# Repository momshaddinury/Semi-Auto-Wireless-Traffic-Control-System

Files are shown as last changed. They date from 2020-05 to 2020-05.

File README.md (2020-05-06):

# Project Name - Lora based Taffic Control System

## Project Members:
* Momshad Dinury
* Abdullah Zowad Khan
* Towqir Ahmed Shaem

## Project Description:
The system is built using devices of two types: node and controller; one controller per system and a maximum of four nodes connected to it. The controller device uses an esp32, a dual-core SoC, with wifi and bluetooth functionalities. The system uses a NEXTION display for the status of the nodes associated with it. For the communication side, LoRa (Long Range) radio module is used. LoRa is widely known for its efficiency in sending short messages quickly and reliably. LoRa uses a transmission method called Chirp Spread Spectrum (CSS) which is used mostly in military and space communications for low power solutions. And lastly, in the nodes, ESP8266 and LoRa are used.

The process begins with the controller rebooting and syncing the nodes. The reboot and sync is done to ensure there is no data loss in regular operations. Each node upon reboot sends a successful boot message, which is used to show the status of the mentioned node.

The signaling is done by pressing specific buttons on the controller. Upon pressing, the controller sends the appropriate signal to the node through LoRa. The system has a timeout of ~15 seconds on communication, after that the attempt is marked as failed. After the node receives the signal, it switches the LEDs on the node then transmits appropriate acknowledgment packets. The display on the controller has a timer so the operator can easily decide whether enough time has passed for a given state at a given lane. The signals sent to each node are independent of the others, which allows the operator to shut down all lanes in case of an emergency.

## Shortcuts
* [**Controller Algorithm Overview**](#controller-algorithm-overview)
* [**Node Algorithm Overview**](#node-algorithm-overview)

## Controller Details

[**Controller.ino**](https://gitlab.com/Momshad/Lora-Traffic-Control-System/blob/Controller-Adjustments-Timers-Displays/Controller/Controller.ino)

### Interrupt Handlers

```cpp
void ISR_DB_1();
void ISR_DB_2();
void ISR_DB_3();
```

Display timers attached to:
```cpp
void Setting_Block_State_Color();
void showTime();
```

## Version 1 Configuration

* Display - TFT
* MCU - esp8266
* Communication - RF (LoRa Module)

## Version 2 Configuration

* Display - 4 Nokia 5110 Transflective Display
* MCU - ESP32
* Communication - Unchanged

### Controller Algorithm Overview
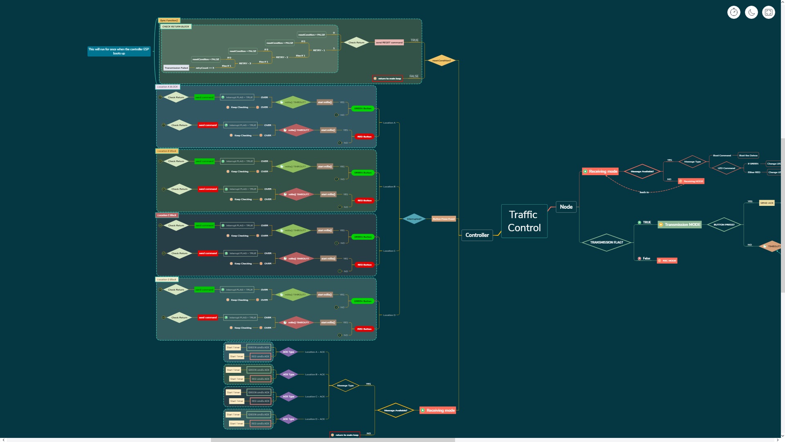
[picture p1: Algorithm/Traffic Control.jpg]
Controller Algorithm


### Node Algorithm Overview
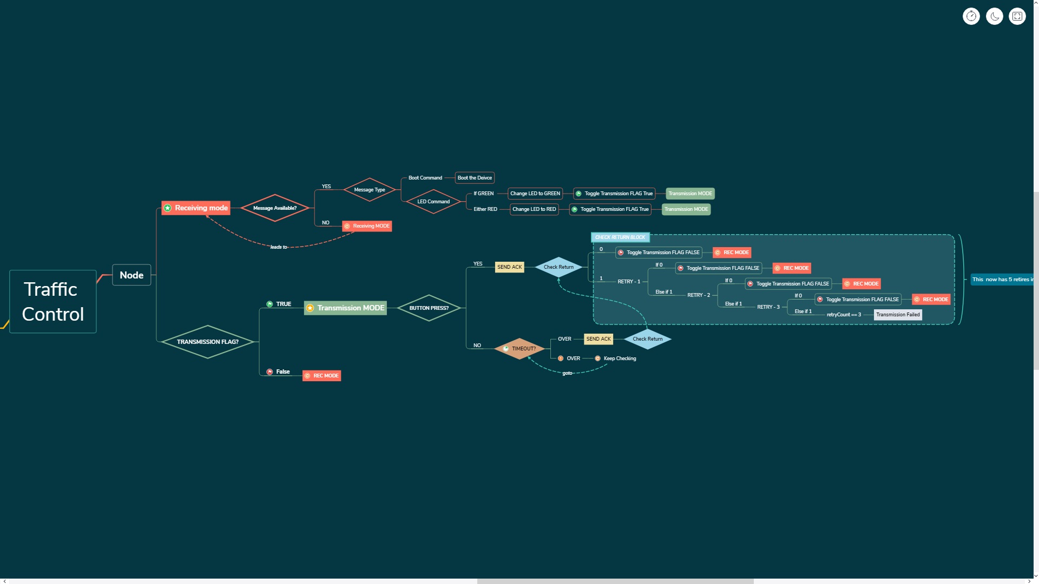
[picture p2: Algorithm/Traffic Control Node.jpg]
Node Algorithm


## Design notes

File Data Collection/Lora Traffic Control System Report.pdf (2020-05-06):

## LoRa Traffic Control System - Project Report

## Current Consumption:

Device | Components | Current Consumption
Controller | Lora | Idle: 14mA

Active: 14mA

NextIon Display | Idle: 107- 110mA
| During changes: 107-112mA
Total Current Consumption | 130mA
Wand | Active State | 160-180mA
| Idle State | 82mA

## Live Test Report:

We tested our device for half an hour in 2 No Gate Circle. It was successful but police recommended few features.

Features Needed:
1. Their baton has the following features:
a. Button pressed, One time - Baton lights up. (Max brightness)
b. Pressed again - Baton light dims slightly.
c. Pressed again - Baton blinks rapidly. (Means emergency)
d. Pressed again - Baton light goes to normal mode and turns on the torch
e. Pressed again - Turns off everything
f. They have another separate button that works as a whistle. In total two buttons
g. Two Day Battery backup.
2. Traffic Control Algorithm: Our algorithm controls each lane individually. But in reality, sergeant controls traffic using a two-stage method. Look at the picture. Sergeant closes TL3 and TL4 opens TL2 and
TL1. When TL3 and TL4
opens they close TL1 and
TL2. So basically it’s simple two-stage control method.
Whereas our controller
controls each lane
individually.

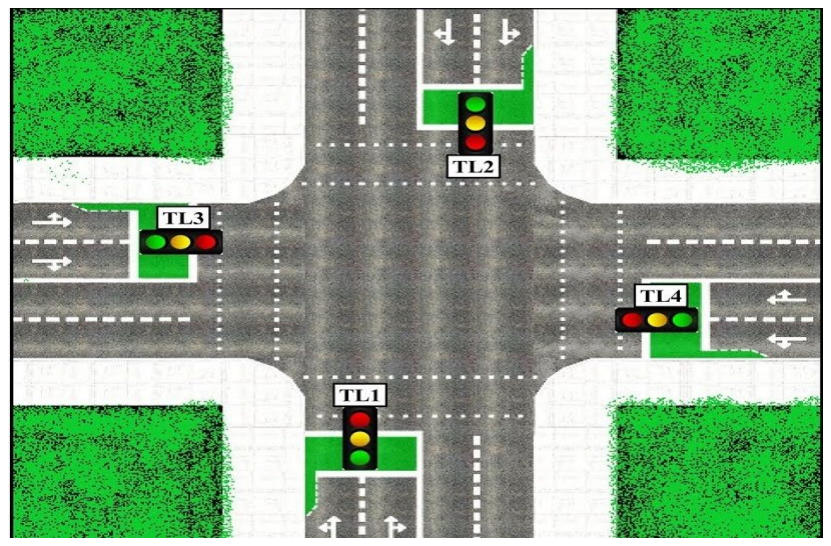
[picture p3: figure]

3. The controller controls baton state as of now, but we need to control Traffic Lights simultaneously with the baton. Basically, one command will change the state of Baton and Traffic Light simultaneously.
4. Automation system. We need to give Sergeant an option that will allow him to automate traffic control. This will be helpful if they are short in the manpower department or if they want to take a break. They can initiate automation mode.
5. The controller needs to be small, easy to carry and lightweight.
6. We need to increase the sunlight visibility of the NextIon Display. ( Using brighter indicator color)

Data: (Link: Data Sheet) (https://docs.google.com/spreadsheets/d/1eQOcHfU4sZK29l6jYq9fvzXtCkEq3vm5WKsJ4Qx3BQA/edit?usp=sharing)

For FSK mode:

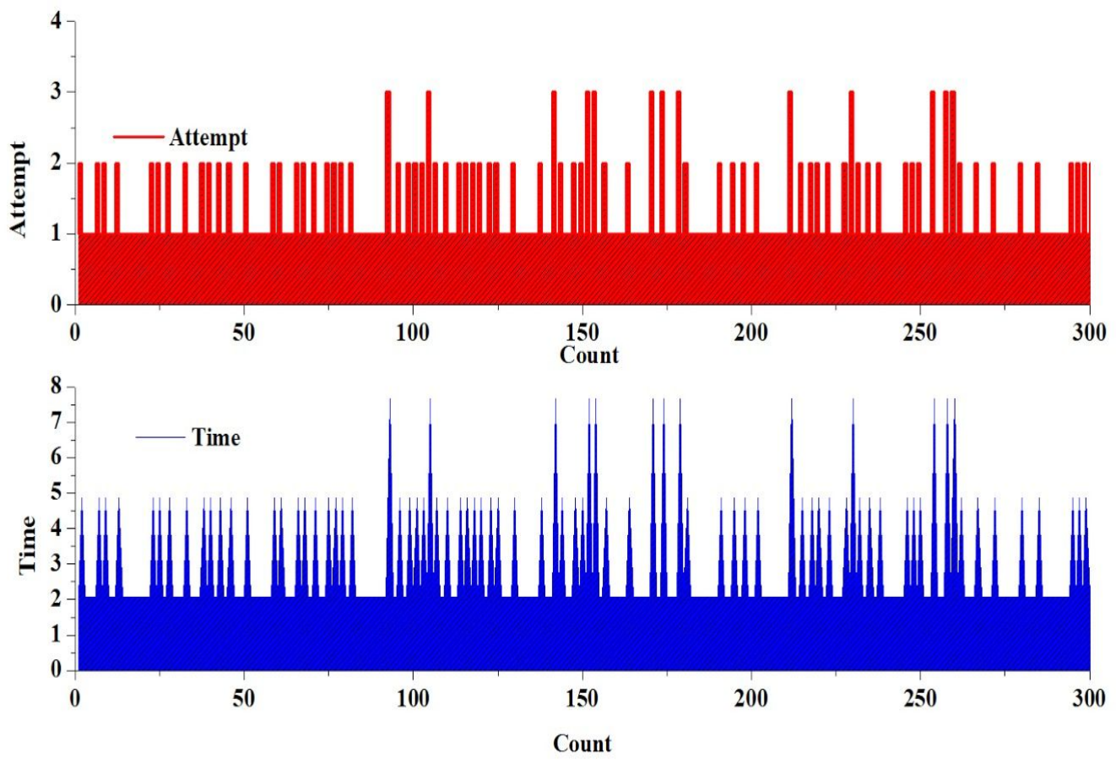
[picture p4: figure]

Time Comparison in OOK mode:

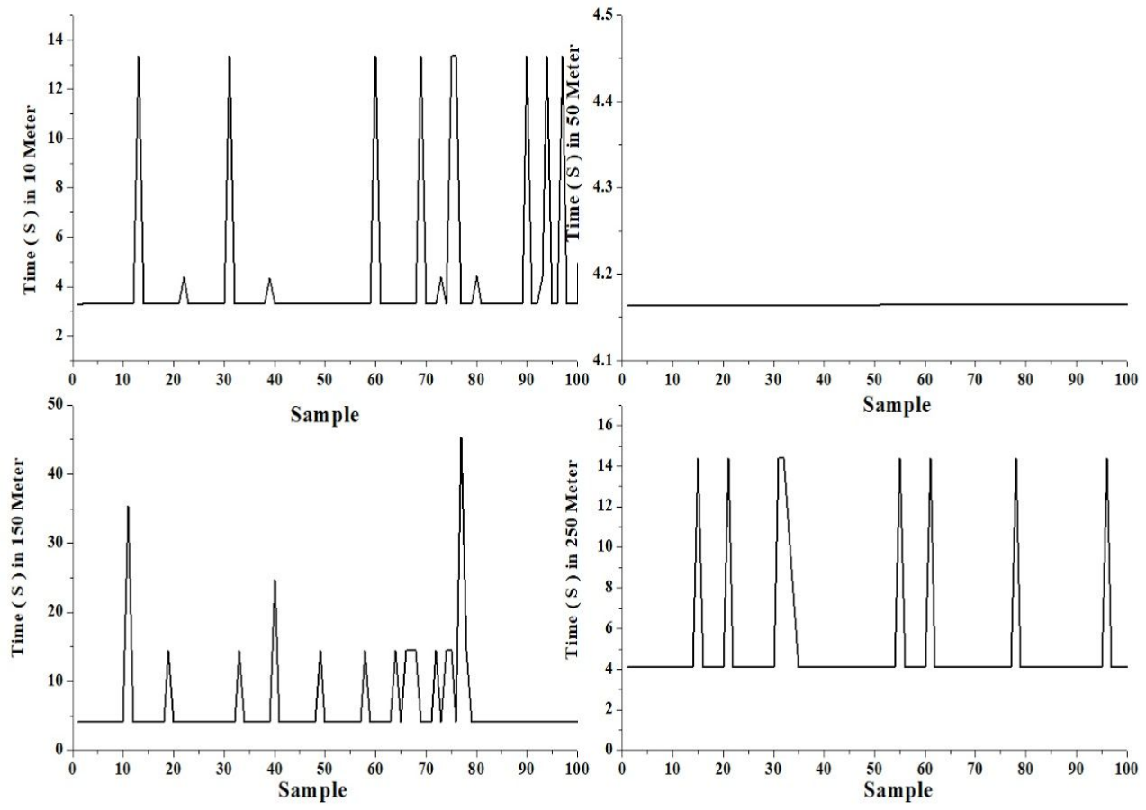
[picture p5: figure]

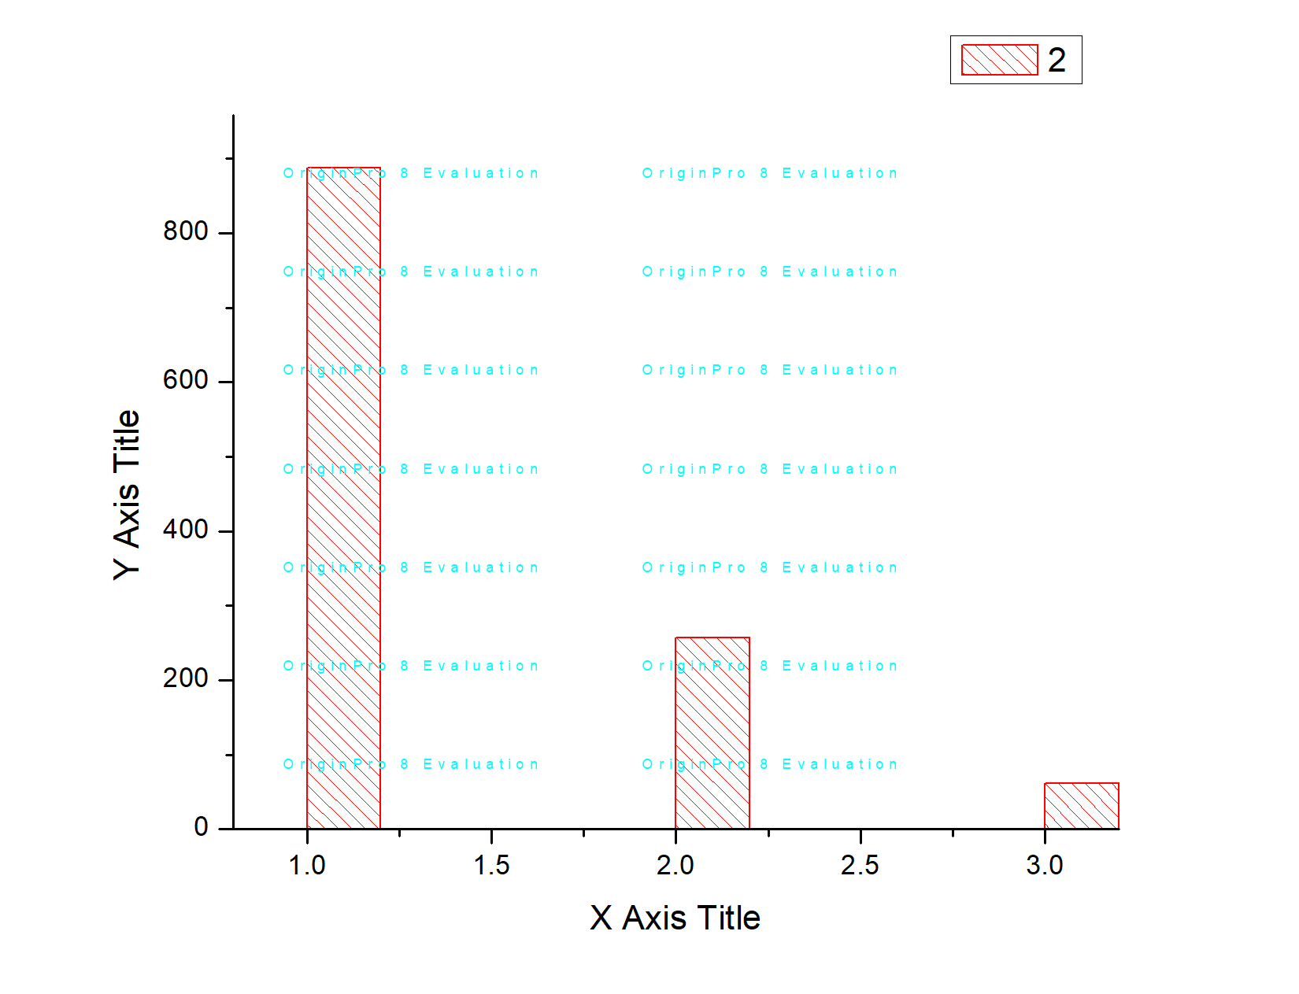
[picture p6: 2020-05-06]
Data Collection/Graph and Corelations/Attempts.jpg

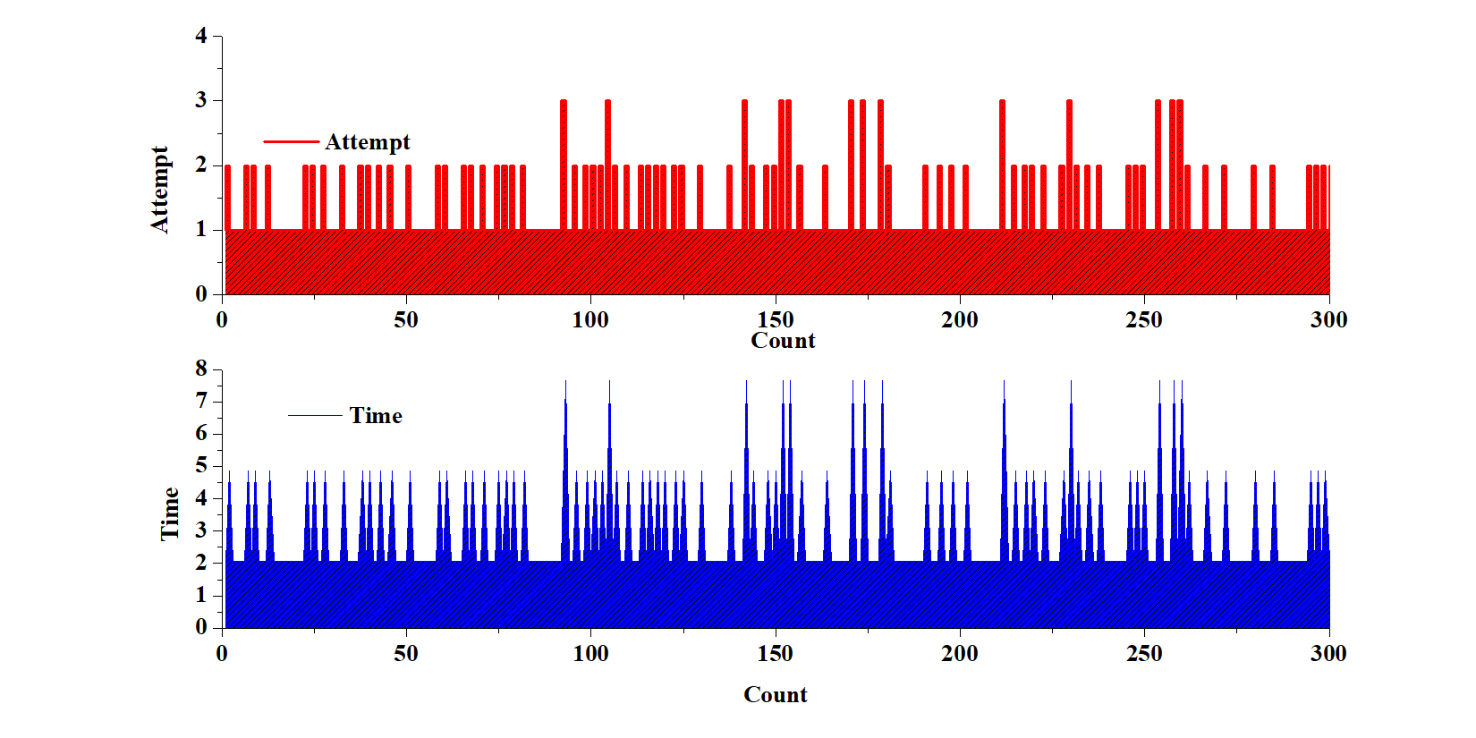
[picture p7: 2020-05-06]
Data Collection/Graph and Corelations/Attemt and Time Vs Counting In FSK.jpg

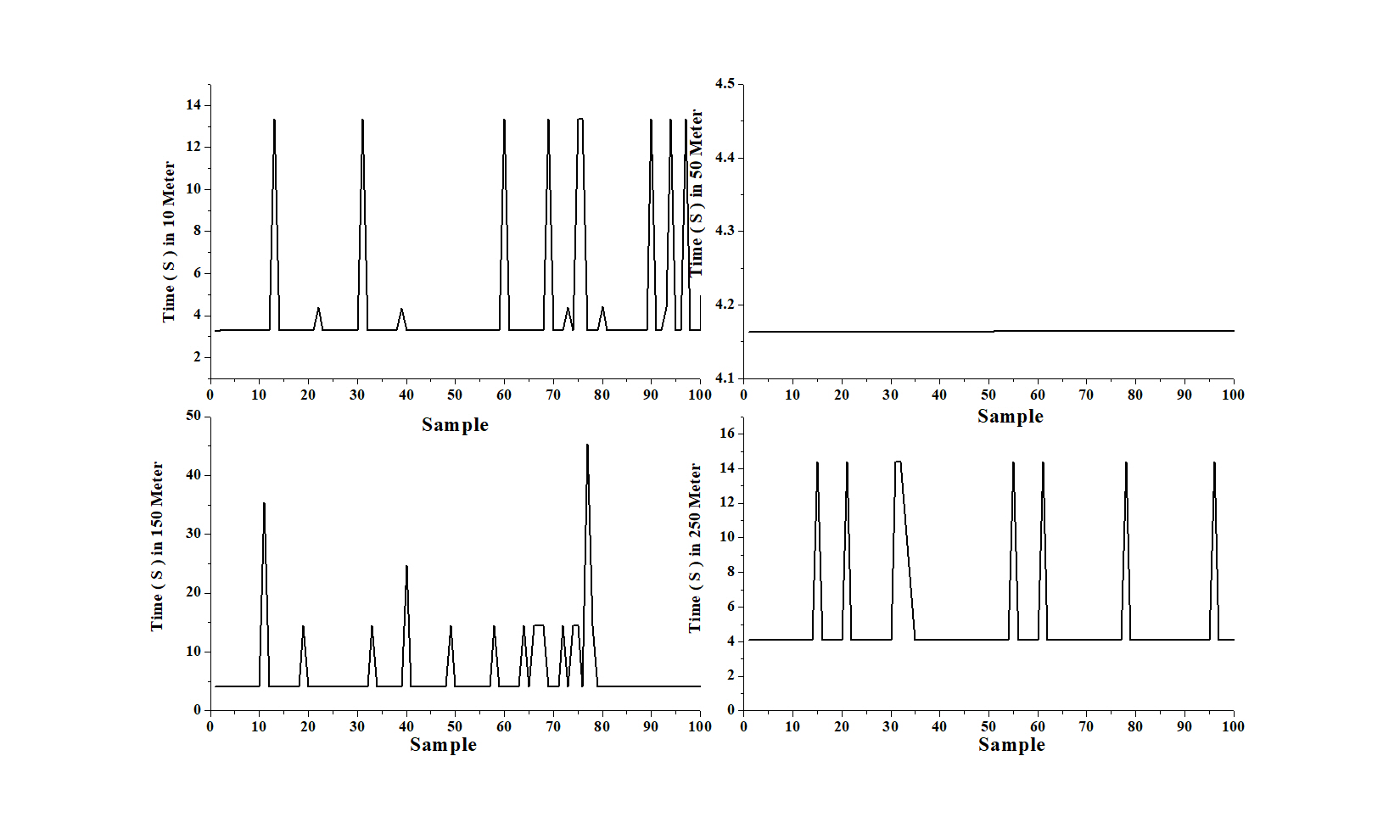
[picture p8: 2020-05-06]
Data Collection/Graph and Corelations/Time Comparision in Distance.jpg

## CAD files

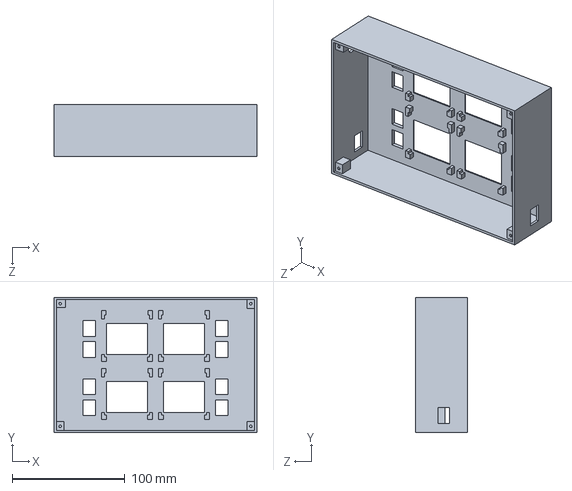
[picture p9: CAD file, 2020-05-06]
3D Design/Controller Box/Box.SLDPRT
180.0 x 120.0 x 46.0 mm

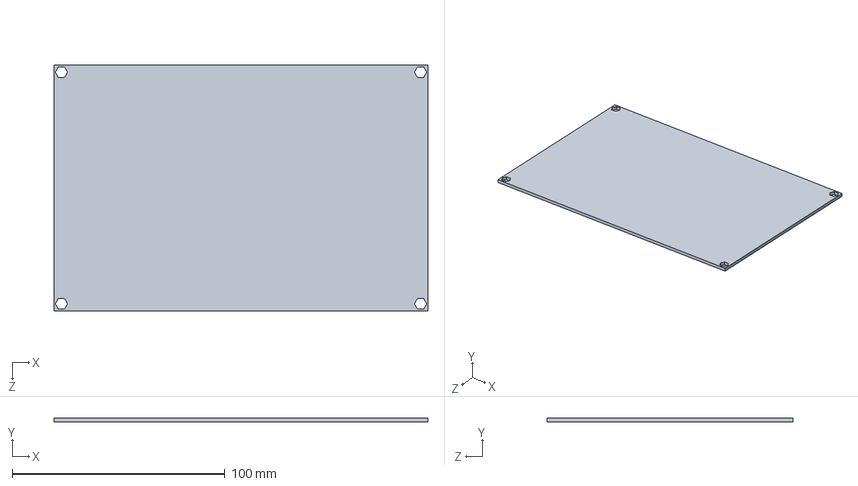
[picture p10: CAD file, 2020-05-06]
3D Design/Controller Box/Bottom Plate.SLDPRT
176.0 x 2.00 x 116.0 mm

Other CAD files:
3D Design/Controller Box/Bottom Plate.STL
3D Design/Controller Box/Box.STL

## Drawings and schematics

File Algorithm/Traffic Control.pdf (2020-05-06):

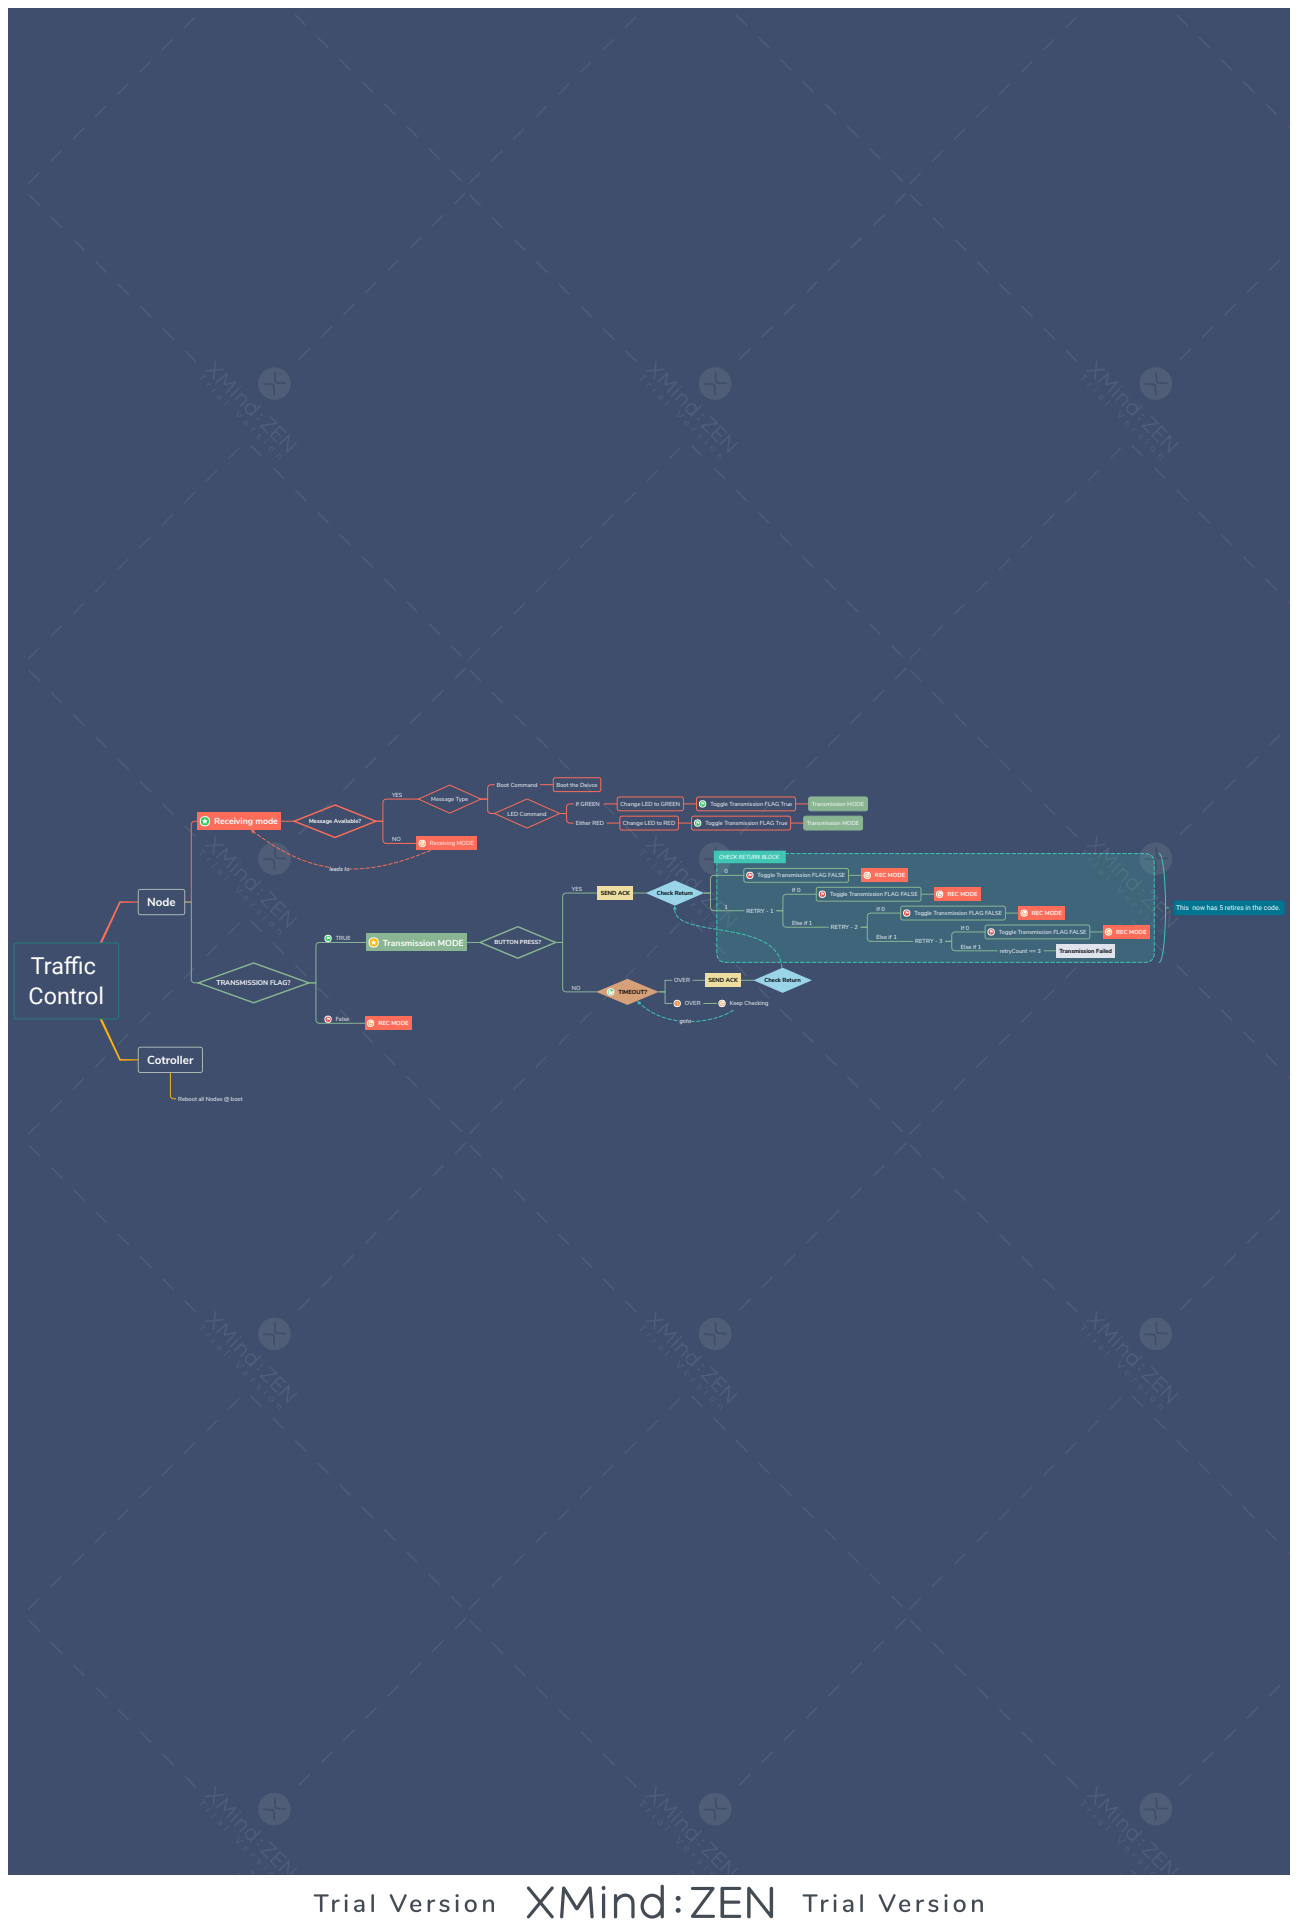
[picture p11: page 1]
Traffic Control; Node; Receiving mode; Message Available?; YES; Message Type; Boot Command; Boot the Deivce; LED Command; If GREEN; Change LED to GREEN; Toggle Transmission FLAG True; Transmission MODE; Either RED; Change LED to RED; Receiving MODE; TRANSMISSION FLAG?; TRUE; BUTTON PRESS?; SEND ACK; Check Return; RETRY - 1; Else if 1; RETRY - 2; RETRY - 3; retryCount == 3; Transmission Failed; TIMEOUT?; OVER; Keep Checking; False; REC MODE; Cotroller; leads to; goto

CHECK RETURN BLOCK

Toggle Transmission FLAG FALSE

This now has 5 retires in the code.

Reboot all Nodes @ boot

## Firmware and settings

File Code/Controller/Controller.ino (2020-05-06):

// ---------------------------------------------------------------------
/*
  Project Name - Semi Automatic Traffic Control System using Lora SX1278
  Components used:
           MCU - ESP32
           Communication module - Lora SX1278 ( FDK Mode )
           Indicator - LED Custom Made Strip
           Power Source - LC 18650
  Author - Momshad Dinury
  Contributor:
           Towqir Ahmed Shaem
           Abdullah Zawad Khan
*/
// ---------------------------------------------------------------------

/******************************************************************************
   Includes
 ******************************************************************************/
#include <Arduino.h>
//Lora SX1278:
#include <SX1278.h>
//Library for Ticker
#include <Ticker.h>
//Library for Display
#include <U8g2lib.h>
#include <WiFi.h>

/*****************************************************************************
   Definitions & Declarations
 *****************************************************************************/

U8G2_PCD8544_84X48_F_4W_HW_SPI u8g1(U8G2_R0, /* cs=*/2, /* dc=*/23, /* reset=*/100);  // Nokia 5110 Display
U8G2_PCD8544_84X48_F_4W_HW_SPI u8g2(U8G2_R0, /* cs=*/4, /* dc=*/23, /* reset=*/100);  // Nokia 5110 Display
U8G2_PCD8544_84X48_F_4W_HW_SPI u8g3(U8G2_R0, /* cs=*/15, /* dc=*/23, /* reset=*/100); // Nokia 5110 Display
U8G2_PCD8544_84X48_F_4W_HW_SPI u8g4(U8G2_R0, /* cs=*/17, /* dc=*/23, /* reset=*/100); // Nokia 5110 Display

//Lora SX1278:
#define LORA_MODE 4
#define LORA_CHANNEL CH_6_BW_125
#define LORA_ADDRESS 5
uint8_t NodeAddress; //Child Address
int address;

#define ADDR_1_INT 3
#define ADDR_1_STR "  GEC CIRCLE"

#define ADDR_2_INT 4
#define ADDR_2_STR "      BAYEZID"

#define ADDR_3_INT 6
#define ADDR_3_STR "      OXYGEN"

#define ADDR_4_INT 7
#define ADDR_4_STR "  MURADPUR"

//Packets var:
char my_packet[50];
char testData[50];
String receivedMsg;
int T_packet_state;
int R_packet_state;

//Pin def of Switch:

#define digitalButton_1 25
#define digitalButton_2 26
#define digitalButton_3 32
#define digitalButton_4 33
#define digitalButton_5 18
#define digitalButton_6 19
#define digitalButton_7 21
#define digitalButton_8 22

// #define digitalButton_3 5
//Experimental

//Signal Time Var:
unsigned long DB_1_Signal_Runtime, DB_2_Signal_Runtime, DB_3_Signal_Runtime, DB_4_Signal_Runtime;
unsigned long currentMil;

//Experimental variables, Color Flags
int colorRG1 = 1, colorRG2 = 1, colorRG3 = 1, colorRG4 = 1;
const int R = 1;
const int G = 2;
const int X = 0;

int attemptDebug = 0;

Ticker location1Sec;

//Sync:
boolean resetCondition = true;

//Timer used to stop debounce @Interrupt Button Press:
long interval = 3000;
volatile unsigned long DB_priv_time_1;
volatile unsigned long DB_priv_time_2;
volatile unsigned long DB_priv_time_3;
volatile unsigned long DB_priv_time_4;
//Interrupt Flag @ISRs Function:
volatile boolean DB_ISR_F_1 = false;
volatile boolean DB_ISR_F_2 = false;
volatile boolean DB_ISR_F_3 = false;
volatile boolean DB_ISR_F_4 = false;

// Button State var @ISRs function:
boolean button1State = true;
boolean button2State = true;
boolean button3State = true;
boolean button4State = true;

boolean is1First = true;
boolean is2First = true;
boolean is3First = true;
boolean is4First = true;

boolean isSyncDone = false;
boolean is1Active = false;
boolean is2Active = false;
boolean is3Active = false;
boolean is4Active = false;

//Transmission Time Calculation Var @InterruptAction():
unsigned long DB_1_Process_Start_Time;
unsigned long DB_1_Process_End_Time;
unsigned long DB_2_Process_Start_Time;
unsigned long DB_2_Process_End_Time;
unsigned long DB_3_Process_Start_Time;
unsigned long DB_3_Process_End_Time;
unsigned long DB_4_Process_Start_Time;
unsigned long DB_4_Process_End_Time;

//Automatic Transmission Flags and Var:
// #define automation
long int autoTime1 = 0;
long int autoTime2 = 0;

//*****
int signalTimeCount = 0;

//Serial Print and Debug:
#define DEBUG
//TESTCASE:
//#define TEST
//#define TESTDEBUG

float t_time;
//Block State Color:
boolean blockStateColor;
int count = 0;

boolean isTransmissionInProgress = false;
boolean isTransmissionInProgress_1 = false;
boolean isTransmissionInProgress_2 = false;
boolean isTransmissionInProgress_3 = false;
boolean isTransmissionInProgress_4 = false;
int countDebug = 1;

//MAIN SETUP FUNCTION
void setup()
{
  // #ifdef DEBUG
  Serial.begin(9600);
  // #endif
  WiFi.mode(WIFI_OFF);
  btStop();
  delay(2000);

  //Display Setup:
  displaySetup();

  // Lora Initialization
  loraSetup();

  //PinMode:
  // 1 Button:
  pinMode(digitalButton_1, INPUT_PULLUP);
  pinMode(digitalButton_2, INPUT_PULLUP);
  // 2 Button:
  pinMode(digitalButton_3, INPUT_PULLUP);
  pinMode(digitalButton_4, INPUT_PULLUP);
  // 3 Button:
  pinMode(digitalButton_5, INPUT_PULLUP);
  pinMode(digitalButton_6, INPUT_PULLUP);
  // 4 Button:
  pinMode(digitalButton_7, INPUT_PULLUP);
  pinMode(digitalButton_8, INPUT_PULLUP);

  pinMode(27, OUTPUT);
  digitalWrite(27, LOW); // To Light Up The Display.

  //Initialization of timers
  DB_1_Signal_Runtime = millis(); //L 1
  DB_2_Signal_Runtime = millis(); //L 2
  DB_3_Signal_Runtime = millis();
  DB_4_Signal_Runtime = millis();

  colorRG1 = X; //L 1
  colorRG2 = X; //L 2
  colorRG3 = X;
  colorRG4 = X;

  //Interrupt Experimental
  attachInterrupt(digitalPinToInterrupt(digitalButton_1), ISR_DB_1_G_32, FALLING);
  attachInterrupt(digitalPinToInterrupt(digitalButton_2), ISR_DB_1_R_32, FALLING);
  attachInterrupt(digitalPinToInterrupt(digitalButton_3), ISR_DB_2_G_32, FALLING);
  attachInterrupt(digitalPinToInterrupt(digitalButton_4), ISR_DB_2_R_32, FALLING);
  attachInterrupt(digitalPinToInterrupt(digitalButton_5), ISR_DB_3_G_32, FALLING);
  attachInterrupt(digitalPinToInterrupt(digitalButton_6), ISR_DB_3_R_32, FALLING);
  attachInterrupt(digitalPinToInterrupt(digitalButton_7), ISR_DB_4_G_32, FALLING);
  attachInterrupt(digitalPinToInterrupt(digitalButton_8), ISR_DB_4_R_32, FALLING);
}

//MAIN LOOP
void loop()
{
  //After the device is booted it automatically re-boots other device:
  sync();

  //  if (countDebug % 2 == 0) ISR_DB_3_G_32();
  //  else ISR_DB_3_R_32();
  //autoTransmission();
  InterruptAction();

  //This function checks for data to receive
  //  if (!isSyncDone)
  //  {
  receiveSync();
  //  }
  //  else recieveData();

  //Show time on display:
  showTime();
  //  delay(500);
}

//RESETs connected Nodes
void sync()
{
  if (resetCondition == true)
  {

    String("S").toCharArray(testData, 50);
    address = ADDR_1_INT;
    sendData2(ADDR_1_INT, testData);
    delay(500);

    receiveSync();

    address = ADDR_2_INT;
    sendData2(ADDR_2_INT, testData);
    delay(500);

    receiveSync();

    address = ADDR_3_INT;
    sendData2(ADDR_3_INT, testData);
    delay(500);

    receiveSync();

    address = ADDR_4_INT;
    sendData2(ADDR_4_INT, testData);
    delay(500);

    //    sendData2(0, testData);

    //    if (T_packet_state == 0)
    //    {
    resetCondition = false;
    delay(1000);
    //    }
  }
}

void receiveSync()
{
  R_packet_state = sx1278.receivePacketTimeoutACK();
  if (R_packet_state == 0)
  {
#ifdef DEBUG
    Serial.println(F("Package received!"));
#endif
    for (unsigned int i = 0; i < sx1278.packet_received.length; i++)
    {
      my_packet[i] = (char)sx1278.packet_received.data[i];
      yield();
    }
#ifdef DEBUG
    Serial.print(F("Message:  "));
    Serial.println(my_packet);
#endif
    receivedMsg = String(my_packet);
    if (receivedMsg == "K01")
    {
      is1Active = is1First = true;
      if (colorRG1 == X)
      {
        u8g1.clearBuffer();                 // clear the internal memory
        u8g1.setFont(u8g2_font_ncenB08_tr); // choose a suitable font
        u8g1.drawStr(0, 10, ADDR_1_STR);
        u8g1.drawStr(25, 20, "Active");
        u8g1.sendBuffer();
      }
      else if (colorRG1 == R)
      {
        ISR_DB_1_R_32();
      }
      else if (colorRG1 == G)
      {
        ISR_DB_1_G_32();
      }
    }
    else if (receivedMsg == "K02")
    {
      is2Active = is2First = true;
      if (colorRG2 == X)
      {
        u8g2.clearBuffer();                 // clear the internal memory
        u8g2.setFont(u8g2_font_ncenB08_tr); // choose a suitable font
        u8g2.drawStr(0, 10, ADDR_2_STR);
        u8g2.drawStr(25, 20, "Active");
        u8g2.sendBuffer();
      }
      else if (colorRG2 == R)
      {
        ISR_DB_2_R_32();
      }
      else if (colorRG2 == G)
      {
        ISR_DB_2_G_32();
      }
    }
    else if (receivedMsg == "K03")
    {
      is3Active = is3First = true;
      if (colorRG3 == X)
      {
        u8g3.clearBuffer();                 // clear the internal memory
        u8g3.setFont(u8g2_font_ncenB08_tr); // choose a suitable font
        u8g3.drawStr(0, 10, ADDR_3_STR);
        u8g3.drawStr(25, 20, "Active");
        u8g3.sendBuffer();
      }
      else if (colorRG3 == R)
      {
        ISR_DB_3_R_32();
      }
      else if (colorRG3 == G)
      {
        ISR_DB_3_G_32();
      }
    }
    else if (receivedMsg == "K04")
    {
      is4Active = is4First = true;
      if (colorRG4 == X)
      {
        u8g4.clearBuffer();                 // clear the internal memory
        u8g4.setFont(u8g2_font_ncenB08_tr); // choose a suitable font
        u8g4.drawStr(0, 10, ADDR_4_STR);
        u8g4.drawStr(25, 20, "Active");
        u8g4.sendBuffer();
      }
      else if (colorRG4 == R)
      {
        ISR_DB_4_R_32();
      }
      else if (colorRG4 == G)
      {
        ISR_DB_4_G_32();
      }
    }
    else
    {
      Setting_Block_State_Color();
    }
    if (is1Active && is2Active && is3Active && is4Active)
    {
      isSyncDone = true;
    }
  }
}

//Experimental esp32 ISRs
void ISR_DB_1_G_32()
{
  if (!button1State && !is1First)
    return;
  if ((long(millis()) - DB_priv_time_1) >= interval)
  {
    DB_ISR_F_1 = true;
    DB_priv_time_1 = millis();
    Serial.print("\n##");
    Serial.print(count += 1);
    Serial.print("\t");
    button1State = true;
  }
}

void ISR_DB_1_R_32()
{
  if (button1State && !is1First)
    return;
  if ((long(millis()) - DB_priv_time_1) >= interval)
  {
    DB_ISR_F_1 = true;
    DB_priv_time_1 = millis();
    Serial.print("\n##");
    Serial.print(count += 1);
    Serial.print("\t");
    button1State = false;
  }
}

void ISR_DB_2_G_32()
{
  if (!button2State && !is2First)
    return;
  if ((long(millis()) - DB_priv_time_2) >= interval)
  {
    DB_ISR_F_2 = true;
    DB_priv_time_2 = millis();
    Serial.print("\n##");
    Serial.print(count += 1);
    Serial.print("\t");
    button2State = true;
  }
}

void ISR_DB_2_R_32()
{
  if (button2State && !is2First)
    return;
  if ((long(millis()) - DB_priv_time_2) >= interval)
  {
    DB_ISR_F_2 = true;
    DB_priv_time_2 = millis();
    Serial.print("\n##");
    Serial.print(count += 1);
    Serial.print("\t");
    button2State = false;
  }
}

void ISR_DB_3_G_32()
{
  if (!button3State && !is3First)
    return;
  if ((long(millis()) - DB_priv_time_3) >= interval)
  {
    DB_ISR_F_3 = true;
    DB_priv_time_3 = millis();
    Serial.print("\n##");
    Serial.print(count += 1);
    Serial.print("\t");
    button3State = true;
  }
}

void ISR_DB_3_R_32()
{
  if (button3State && !is3First)
    return;
  if ((long(millis()) - DB_priv_time_3) >= interval)
  {
    DB_ISR_F_3 = true;
    DB_priv_time_3 = millis();
    Serial.print("\n##");
    Serial.print(count += 1);
    Serial.print("\t");
    button3State = false;
  }
}

void ISR_DB_4_G_32()
{
  if (!button4State && !is4First)
    return;
  if ((long(millis()) - DB_priv_time_4) >= interval)
  {
    DB_ISR_F_4 = true;
    DB_priv_time_4 = millis();
    Serial.print("\n##");
    Serial.print(count += 1);
    Serial.print("\t");
    button4State = true;
  }
}

void ISR_DB_4_R_32()
{
  if (button4State && !is4First)
    return;
  if ((long(millis()) - DB_priv_time_4) >= interval)
  {
    DB_ISR_F_4 = true;
    DB_priv_time_4 = millis();
    Serial.print("\n##");
    Serial.print(count += 1);
    Serial.print("\t");
    button4State = false;
  }
}

//States what happens when InterruptAction Function is called:
void InterruptAction()
{

  if (DB_ISR_F_1)
  {
    DB_1_Process_Start_Time = millis();

    colorRG1 = X;

    if (button1State)
    {
#ifdef DEBUG
      Serial.println("\nButton 1 was pressed once!");
#endif

#ifdef TEST
      Serial.print("##");
      Serial.print(count += 1);
      Serial.print("\t");
#endif

      String("GL1").toCharArray(testData, 50);
      address = 3;
      sendData(address, testData);

      if (T_packet_state == 0)
      {
        blockStateColor = true;
        button1State = false;
      }
      else
      {
        button1State = true;
      }
#ifndef TEST
      DB_ISR_F_1 = false;
#endif
    }
    else if (!button1State)
    {

#ifdef DEBUG
      Serial.println("\nButton 1 was pressed twice!");
#endif

#ifdef TEST
      Serial.print("##");
      Serial.print(count += 1);
      Serial.print("\t");
#endif

      String("RL1").toCharArray(testData, 50);
      address = 3;
      sendData(address, testData);

      if (T_packet_state == 0)
      {
        blockStateColor = false;
        button1State = true;
      }
      else
      {
        button1State = false;
      }

#ifndef TEST
      DB_ISR_F_1 = false;
#endif
    }
  }

  else if (DB_ISR_F_2)
  {
    DB_2_Process_Start_Time = millis();

    colorRG2 = X;

    if (button2State)
    {
#ifdef DEBUG
      Serial.println("\nButton 2 was pressed once!");
#endif

      String("GL2").toCharArray(testData, 50);
      address = 4;
      sendData(address, testData);

      if (T_packet_state == 0)
      {
        blockStateColor = true;
        button2State = false;
      }
      else
      {
        button2State = true;
      }

      DB_ISR_F_2 = false;
    }
    else if (!button2State)
    {
#ifdef DEBUG
      Serial.println("\nButton 2 was pressed twice!");
#endif

      String("RL2").toCharArray(testData, 50);
      address = 4;
      sendData(address, testData);

      if (T_packet_state == 0)
      {
        blockStateColor = false;
        button2State = true;
      }
      else
      {
        button2State = false;
      }
      DB_ISR_F_2 = false;
    }
  }
  // DB 3:
  else if (DB_ISR_F_3)
  {
    DB_3_Process_Start_Time = millis();

    colorRG3 = X;

    if (button3State)
    {
#ifdef DEBUG
      Serial.println("\nButton 3 was pressed once!");
#endif

      String("GL3").toCharArray(testData, 50);
      address = 6;
      sendData(address, testData);

      if (T_packet_state == 0)
      {
        blockStateColor = true;
        button3State = false;
      }
      else
      {
        button3State = true;
      }
      DB_ISR_F_3 = false;
    }
    else if (!button3State)
    {
#ifdef DEBUG
      Serial.println("\nButton 3 was pressed twice!");
#endif

      String("RL3").toCharArray(testData, 50);
      address = 6;
      sendData(address, testData);

      if (T_packet_state == 0)
      {
        blockStateColor = false;
        button3State = true;
      }
      else
      {
        button3State = false;
      }
      DB_ISR_F_3 = false;
    }
  }

  else if (DB_ISR_F_4)
  {
    DB_4_Process_Start_Time = millis();

    colorRG4 = X;

    if (button4State)
    {
#ifdef DEBUG
      Serial.println("\nButton 4 was pressed once!");
#endif

      String("GL4").toCharArray(testData, 50);
      address = 7;
      sendData(address, testData);

      if (T_packet_state == 0)
      {
        blockStateColor = true;
        button4State = false;
      }
      else
      {
        button4State = true;
      }

      DB_ISR_F_4 = false;
    }
    else if (!button4State)
    {
#ifdef DEBUG
      Serial.println("\nButton 4 was pressed twice!");
#endif

      String("RL4").toCharArray(testData, 50);
      address = 7;
      sendData(address, testData);

      if (T_packet_state == 0)
      {
        blockStateColor = false;
        button4State = true;
      }
      else
      {
        button4State = false;
      }
      DB_ISR_F_4 = false;
    }
  }
}

/*
  Function: Configures the module to transmit information and receive an ACK.
  Returns: Integer that determines if there has been any error [T_packet_state]
   state = 9  --> The ACK lost (no data available)
   state = 8  --> The ACK lost
   state = 7  --> The ACK destination incorrectly received
   state = 6  --> The ACK source incorrectly received
   state = 5  --> The ACK number incorrectly received
   state = 4  --> The ACK length incorrectly received
   state = 3  --> N-ACK received
   state = 2  --> The command has not been executed
   state = 1  --> There has been an error while executing the command
   state = 0  --> The command has been executed with no errors
*/
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

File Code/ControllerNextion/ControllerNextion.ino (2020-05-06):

// ---------------------------------------------------------------------
/*
  Project Name - Semi Automatic Traffic Control System using Lora SX1278
  Components used:
           MCU - ESP32
           Communication module - Lora SX1278 ( FSK Mode )
           Display - Nextion 3.5"
           Power Source - LC 18650
  Author - Momshad Dinury
  Contributor:
           Abdullah Zowad Khan
           Towqir Ahmed Shaem
           
*/
// ---------------------------------------------------------------------

/******************************************************************************
   Includes
 ******************************************************************************/
#include <Arduino.h>
//Lora SX1278:
#include <SX1278.h>
//Library for Ticker
#include <Ticker.h>
//Library for Display
#include <U8g2lib.h>
#include <WiFi.h>

//DEBUG FLAGS:
// #define DEBUG_ALL
// #define DEBUG_DISPLAY
#define DEBUG_TRANSMISSION
#define DEBUG_FUNCTION_CALL
#define DEBUG_INTERRUPT

#ifdef DEBUG_ALL
#define DEBUG_DISPLAY
#define DEBUG_TRANSMISSION
#define DEBUG_FUNCTION_CALL
#define DEBUG_INTERRUPT
#endif

#define CONTROLLER
int attemptDebug = 0;
int countDebug = 1;

/*****************************************************************************
   Definitions & Declarations
 *****************************************************************************/

//Lora SX1278:
#define LORA_SS_Pin 5 //ESP32
#define LORA_MODE 4
#define LORA_CHANNEL CH_6_BW_125
#define LORA_ADDRESS 5
uint8_t NodeAddress; //Child Address
int address;

//Packets var:
char my_packet[50];
char testData[50];
String receivedMsg;
int T_packet_state;
int R_packet_state;

//NEXTION Color values
#define NEXTION_RED "63488"
#define NEXTION_DARK_RED "43008"
#define NEXTION_BLACK "0"
#define NEXTION_GREEN "1632"
#define NEXTION_LIGHT_GREEN "2016"
#define NEXTION_DARK_GREEN "512"
#define NEXTION_BLUE "31"
#define NEXTION_WHITE "65535"

#define NEXTION_LOCATION_1 "t0"
#define NEXTION_LOCATION_2 "t1"
#define NEXTION_LOCATION_3 "t2"
#define NEXTION_LOCATION_4 "t3"

#define NEXTION_STATUS_1 "t4"
#define NEXTION_STATUS_2 "t5"
#define NEXTION_STATUS_3 "t6"
#define NEXTION_STATUS_4 "t7"

#define NEXTION_TRANSMISSION_1 "t12"
#define NEXTION_TRANSMISSION_2 "t13"
#define NEXTION_TRANSMISSION_3 "t14"
#define NEXTION_TRANSMISSION_4 "t15"

#define NEXTION_TIMER_1 "t8"
#define NEXTION_TIMER_2 "t9"
#define NEXTION_TIMER_3 "t10"
#define NEXTION_TIMER_4 "t11"

#define NEXTION_COMMAND_TEXT "txt"
#define NEXTION_COMMAND_BACKGROUND "bco"
#define NEXTION_FOREGROUND_TEXT_COLOR "pco"

#define ADDR_1_INT 3
#define ADDR_1_STR "LANE 1"

#define ADDR_2_INT 4
#define ADDR_2_STR "LANE 2"

#define ADDR_3_INT 6
#define ADDR_3_STR "LANE 3"

#define ADDR_4_INT 7
#define ADDR_4_STR "LANE 4"

//Signal Time Var:
unsigned long DB_1_Signal_Runtime, DB_2_Signal_Runtime, DB_3_Signal_Runtime, DB_4_Signal_Runtime;
unsigned long currentMil;

//Color Flags:
int colorRG1 = 1, colorRG2 = 1, colorRG3 = 1, colorRG4 = 1;
const int R = 1;
const int G = 2;
const int X = 0;
//Checking Transmission State:
boolean isTransmissionInProgress = false;
boolean isTransmissionInProgress_1 = false;
boolean isTransmissionInProgress_2 = false;
boolean isTransmissionInProgress_3 = false;
boolean isTransmissionInProgress_4 = false;

//Pin def of Switch:
#define digitalButton_1 25
#define digitalButton_2 26
#define digitalButton_3 32
#define digitalButton_4 33
#define digitalButton_5 18
#define digitalButton_6 19
#define digitalButton_7 21
#define digitalButton_8 22

//Timer used to stop debounce @Interrupt Button Press:
long interval = 3000;
volatile unsigned long DB_priv_time_1;
volatile unsigned long DB_priv_time_2;
volatile unsigned long DB_priv_time_3;
volatile unsigned long DB_priv_time_4;

//Interrupt Flag @ISRs Function Flags:
volatile boolean DB_ISR_F_1 = false;
volatile boolean DB_ISR_F_2 = false;
volatile boolean DB_ISR_F_3 = false;
volatile boolean DB_ISR_F_4 = false;

// Button State var @ISRs function:
boolean button1State = true;
boolean button2State = true;
boolean button3State = true;
boolean button4State = true;

// First Button Press Flag
boolean is1First = true;
boolean is2First = true;
boolean is3First = true;
boolean is4First = true;

//Sync:
boolean resetCondition = true;
boolean isSyncDone = false;
boolean is1Active = false;
boolean is2Active = false;
boolean is3Active = false;
boolean is4Active = false;

//Transmission Time Calculation Var @InterruptAction():
unsigned long DB_1_Process_Start_Time;
unsigned long DB_1_Process_End_Time;
unsigned long DB_2_Process_Start_Time;
unsigned long DB_2_Process_End_Time;
unsigned long DB_3_Process_Start_Time;
unsigned long DB_3_Process_End_Time;
unsigned long DB_4_Process_Start_Time;
unsigned long DB_4_Process_End_Time;

unsigned long firstTime;
unsigned long secondTime;

//Automatic Transmission Flags and Var:
// #define automation
long int autoTime1 = 0;
long int autoTime2 = 0;

int signalTimeCount = 0;

float t_time;
//Block State Color:
boolean blockStateColor;
int count = 0;

int syncCounter = 0;

//MAIN SETUP FUNCTION
void setup()
{
  Serial.begin(9600);
  Serial2.begin(57600);

  WiFi.mode(WIFI_OFF);
  btStop();
  delay(2000);

  //Display Setup:
  displaySetup();

  //Initialization of display timers
  DB_1_Signal_Runtime = millis();
  DB_2_Signal_Runtime = millis();
  DB_3_Signal_Runtime = millis();
  DB_4_Signal_Runtime = millis();
  colorRG1 = colorRG2 = colorRG3 = colorRG4 = X;

  // Lora Initialization
  loraSetup();

  //PinMode:
  // 1 Button:
  pinMode(digitalButton_1, INPUT_PULLUP);
  pinMode(digitalButton_2, INPUT_PULLUP);
  // 2 Button:
  pinMode(digitalButton_3, INPUT_PULLUP);
  pinMode(digitalButton_4, INPUT_PULLUP);
  // 3 Button:
  pinMode(digitalButton_5, INPUT_PULLUP);
  pinMode(digitalButton_6, INPUT_PULLUP);
  // 4 Button:
  pinMode(digitalButton_7, INPUT_PULLUP);
  pinMode(digitalButton_8, INPUT_PULLUP);

  //Interrupt Experimental
  attachInterrupt(digitalPinToInterrupt(digitalButton_1), ISR_DB_1_G_32, FALLING);
  attachInterrupt(digitalPinToInterrupt(digitalButton_2), ISR_DB_1_R_32, FALLING);
  attachInterrupt(digitalPinToInterrupt(digitalButton_3), ISR_DB_2_G_32, FALLING);
  attachInterrupt(digitalPinToInterrupt(digitalButton_4), ISR_DB_2_R_32, FALLING);
  attachInterrupt(digitalPinToInterrupt(digitalButton_5), ISR_DB_3_G_32, FALLING);
  attachInterrupt(digitalPinToInterrupt(digitalButton_6), ISR_DB_3_R_32, FALLING);
  attachInterrupt(digitalPinToInterrupt(digitalButton_7), ISR_DB_4_G_32, FALLING);
  attachInterrupt(digitalPinToInterrupt(digitalButton_8), ISR_DB_4_R_32, FALLING);
}
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

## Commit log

2018-03-19 Controller code added.
    Sends specific msg on specific button press to another Lora module successfully
2018-03-26 Made lots of changs
    Added folder
    PCB design Added
    Lane Wand code using Lora Added
    Controller code using Lora and SPI display added
2018-04-03 Fixes:
    -RX pin used as Data pin for LED STRIP.
    -setColor function used for processing received packet
    -Added lora code
    [Node.ino]
2018-04-03 Button value fixed sendData function modified
    Code working
    [Controller.ino]
2018-06-10 Node code using Interrupt
2018-07-09 Working Code. Lots of changes made.
    Instead of NeoPixel LED the plan is now to use Combination of separate LEDs to Indicate yellow and green color.
    Total algorithm is now changed.
    1. Sync feature - When the device boots (Controller) it will automatically boot other Lane Wands to maintain Sync.
    2. Data Collision- As this whole system runs on single channel msg often collides w one another. If this should happen the Node will be suppressed. Controller msg will be taken into consideration while both tries to send data.
    3. Fail Safe - If the device should fail to send data and get ACK it will keep trying untill it sends the message successfully.
    4. 2 way confirmation - When the controller s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
    [Controller.ino, Node.ino]
2018-07-14 Interrupt overlapping solved on Controller. Now sends unique command and gets unique respose based on Location. Red Led Added.
    **Issue: In Controller - Analog button value overlaps. Sometimes
    **Issue: Occassionally both device sends garbage that causes receiving end device to restart. Rare.
    **Issue: Lane wand faced one Soft WDT will figure out the cause.
    [Controller.ino, Node.ino]
2018-10-18 Deleted current folders
2018-10-18 Added Data Collection Folder
    [Project Data.xlsx]
2018-11-12 Location 1 Block Timer Reupload
2018-11-18 Added files and formatted the code, made few syntax change overall everything is all the same
    [Project Data.xlsx]
2018-12-04 Repo - 04-Dec-18-1645 changed buttons, erratic state 1 appears
2018-12-24 Trying to fix state_1
    Attempts:
    1. Manual button press data transmission, Faced state_1 error
    2. Tried Automatic data transmission including updating display, result no state_1 even after 100+ transmission.
    Issue: May be hardware short circuit while manually pressing button
    [Controller.ino]
2018-12-25 Lora Traffic Control schematic with esp32 and nokia 5110 display
2018-12-25 Component's Footprint
2018-12-26 Solved state 1
    Changes made:
    Disabled the Ticker as it was causing state 1 in Lora.
    Now show Time() is directly used at loop() and shows real time update.
    All the other related problem like Restart and slow data transfer was casued by conflict between Interrupt & Ticker call.
    Now all Issue resolved
    [Controller.ino]
2018-12-27 Organized Folders
    PCB folder is organized.
    Added Components Folder, Library Folder.
    Sorted Controller Schematic and PCB file in a Controller Folder.
    Created a new Node Folder.
    Algorithm folder is now at the main directory.
2018-12-27 Whole systerm Working
    Controller:
    additional 4 digital buttons added.
    4 more ISRs added
    Display function added.
    Node code formatted. Working for all four locations
2019-02-21 Moderated Display Dimension
    27 No pIn Connected With BL
2019-02-21 Power Button Added
2019-03-16 Node PCB & Schematic File added
2019-03-27 Button and Display allignmented
2019-03-30 Attempt at parallel functions * Retries out of the library * Connecting test on display (requires test to see if there's a massive mess) * No timer reset on same functions (AGAIN SEE IF THERE'S A MAS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
    [Controller.ino]
2019-03-31 LED Blinking Mechanism
2019-03-31 Data Trasmission and LED Blinking Moderated
    Required time of Data Receive Changed.
    LED Blinking Interval Time Chnaged.
2019-04-06 Added auto resume of signal light upon reset TESTS NEEDED
    [Controller.ino]
2019-04-08 3D Design Files Added (Controller Box)
    [Bottom Plate.SLDPRT, Bottom Plate.STL, Box.SLDPRT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]
2019-04-09 fixed id errors, added font
    [ControllerNextion.ino]
2019-04-16 Few minor bug fixed
    [ControllerNextion.ino, Node.ino]
2019-04-22 Made changes in Node file. Adding manual button control. (in progress)
2019-04-27 Manual button bug fixed
    [Node.ino]
2019-06-15 added buttonstates to remember state on "From Lane"
